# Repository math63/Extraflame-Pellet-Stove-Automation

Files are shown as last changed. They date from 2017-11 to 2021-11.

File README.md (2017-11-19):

# Extraflame-Pellet-Stove-Automation

https://pcbs.io/share/42JMy

https://www.sculpteo.com/fr/print_old/boite_v2-10/cqvDiYiF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

https://circuits.io/circuits/5604341-arduinorfm95-v6

Comments :
In mysensors plugin for jeedom, change baudrate from 115200 to 38400 :
Mysensors/Node/mysensors.js

```
var SerialPort = require('serialport');
	gw = new SerialPort(gwAddress);
        //compatibilité avec la nouvelle verion de serialport
        if ( gw.settings.baudRate ){
                gw.settings.baudRate=38400;
        }else{
                gw.settings.baudrate=38400;
        }
```

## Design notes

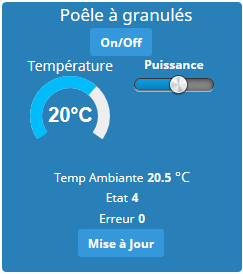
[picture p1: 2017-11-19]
Jeedom/Jeedom.png

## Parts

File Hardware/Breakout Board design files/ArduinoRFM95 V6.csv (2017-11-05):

Part | Value |  |  |  | Device | Package | Description | MPN | PROD_ID | VALUE
C1 | 0.1uF | 0603 0.1uF 50V 10% SMD Multilayer Ceramic Chip Capacitor | 0,0057 | aliexpress (seller don't exist anymore) | CAP0603-CAP | 0603-CAP | Capacitor
C2 | 0.1uF | 0603 0.1uF 50V 10% SMD Multilayer Ceramic Chip Capacitor | 0,0057 | aliexpress (seller don't exist anymore) | CAP0603-CAP | 0603-CAP | Capacitor
C3 | 0.1uF | 0603 0.1uF 50V 10% SMD Multilayer Ceramic Chip Capacitor | 0,0057 | aliexpress (seller don't exist anymore) | CAP0603-CAP | 0603-CAP | Capacitor
C4 | 10uF | Tantalum capacitor 10uf 16v type B 3528 (1210) | 0,13 |  | CAP_POL3528-KIT | EIA3528-KIT | Capacitor Polarized
C5 | 0.1uF | 0603 0.1uF 50V 10% SMD Multilayer Ceramic Chip Capacitor | 0,0057 | aliexpress (seller don't exist anymore) | CAP0603-CAP | 0603-CAP | Capacitor
C6 | 0.1uF | 0603 0.1uF 50V 10% SMD Multilayer Ceramic Chip Capacitor | 0,0057 | aliexpress (seller don't exist anymore) | CAP0603-CAP | 0603-CAP | Capacitor
C7 | 47pF |  |  |  | CAP0603-CAP | 0603-CAP | Capacitor
C8 | 47pF |  |  |  | CAP0603-CAP | 0603-CAP | Capacitor
C9 | 0.1uF | 0603 0.1uF 50V 10% SMD Multilayer Ceramic Chip Capacitor | 0,0057 | aliexpress (seller don't exist anymore) | CAP0603-CAP | 0603-CAP | Capacitor
C10 | 0.1uF | 0603 0.1uF 50V 10% SMD Multilayer Ceramic Chip Capacitor | 0,0057 | aliexpress (seller don't exist anymore) | CAP0603-CAP | 0603-CAP | Capacitor
C11 | 0.1uF | 0603 0.1uF 50V 10% SMD Multilayer Ceramic Chip Capacitor | 0,0057 | aliexpress (seller don't exist anymore) | CAP0603-CAP | 0603-CAP | Capacitor
C12 | 10uF | Tantalum capacitor 10uf 16v type B 3528 (1210) | 0,13 |  | CAP_POL3528-KIT | EIA3528-KIT | Capacitor Polarized
C13 | 1uF | 0603 1UF ceramic capacitor | 0,0086 | https://www.aliexpress.com/item/100PCS-0603-1UF-105-1000NF-10V-Y5V-Ceramic-capacitors-Good-Quality-and-ROHS/1091059510.html | CAP0603-CAP | 0603-CAP | Capacitor
C14 | 10uF | Tantalum capacitor 10uf 16v type B 3528 (1210) | 0,13 |  | CAP_POL3528-KIT | EIA3528-KIT | Capacitor Polarized
C15 | 0.1uF | 0603 0.1uF 50V 10% SMD Multilayer Ceramic Chip Capacitor | 0,0057 | aliexpress (seller don't exist anymore) | CAP0603-CAP | 0603-CAP | Capacitor
C16 | 18pF | GRM1885C1H180JA01J | 0,0418 | http://fr.farnell.com/murata/grm1885c1h180ja01j/condensateur-mlcc-c0g-18pf-50v/dp/2611915?CMP=i-bf9f-00001000 | CAP0603-CAP | 0603-CAP | Capacitor
C17 | 18pF | GRM1885C1H180JA01J | 0,0418 | http://fr.farnell.com/murata/grm1885c1h180ja01j/condensateur-mlcc-c0g-18pf-50v/dp/2611915?CMP=i-bf9f-00001000 | CAP0603-CAP | 0603-CAP | Capacitor
D1 | YELLOW | 0603 SMD LED Kits | 0,03 | https://www.aliexpress.com/item/0603-SMD-LED-Kits-Red-Yellow-Blue-Green-White-5-colors-each-20pcs/32552321637.html | LEDCHIP-LED0603 | CHIP-LED0603 | LED
D2 | RED | 0603 SMD LED Kits | 0,03 | https://www.aliexpress.com/item/0603-SMD-LED-Kits-Red-Yellow-Blue-Green-White-5-colors-each-20pcs/32552321637.html | LEDCHIP-LED0603 | CHIP-LED0603 | LED
F1 | MF-MSMF050-2 | MF-MSMF050-2 | 0,105 | https://www.aliexpress.com/item/10PCS-MF-MSMF050-2-MF-MSMF050-PTC-RESETTABLE-FUSE-0-5A-500MA-15V-For-BOURNS-1812/32633390844.html | SMD-PPTC-FUSE-PPTC-0.50A-15V-0.15OHM(1812) | F1812 | 307010040 | MF-MSMF050-2 |  | MF-MSMF050-2
FRAME1 | FRAME-LETTER |  |  |  | FRAME-LETTER | CREATIVE_COMMONS | Schematic Frame
J2 | AVR_SPI_PRG_6PTH | 2.54mm 2 x 40 Pin Male Double Row | 0,12 | https://www.aliexpress.com/item/5-PCS-2-54mm-2-x-40-Pin-Male-Double-Row-Pin-Header-Strip/32216818428.html | AVR_SPI_PRG_6PTH | 2X3 | AVR ISP 6 Pin
J3 | USB-SMD-NS | Mini USB Type B SMD Female Socket 5-Pin | 0,75 | aliexpress (seller don't exist anymore) | USB-SMD-NS | USB-MINIB-NOSTOP | USB Connectors
J4 |  |  |  |  | M161X16_NO_SILK | 1X16_NO_SILK | 1x16 .1 header"
J5 |  |  |  |  | M161X16_NO_SILK | 1X16_NO_SILK | 1x16 .1 header"
JP3 |  |  |  |  | M01NOSILK-KIT | 1X01NS-KIT | Header 1
Q1 | FDN360P | FDN360P | 0,362 | http://fr.farnell.com/on-semiconductor-fairchild/fdn360p/transistor-mosfet-p-sot-23/dp/9846336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 | MOSFET-PCHANNELSMD | SOT23-3 | Generic PMOSFET
Q2 | MOSFET-NCHANNEL2N7002PW |  |  |  | MOSFET-NCHANNEL2N7002PW | SOT323 | Common NMOSFET Parts |  | TRANS-11151
Q3 | PMV48XP | PMV48XP P-channel MOSFET | 0,19 | https://www.aliexpress.com/item/Free-shipping-10pcs-lot-PMV48XP-P-channel-MOSFET-FET-SOT-23-new-original/32558117050.html | MOSFET-PCHANNELSMD | SOT23-3 | Generic PMOSFET
R1 | 10K | Resistor 1% 0603 10K | 0,0044 | aliexpress (seller don't exist anymore) | RESISTOR0603-RES | 0603-RES | Resistor
R2 | 27R |  |  |  | RESISTOR0603-RES | 0603-RES | Resistor
R3 | 27R |  |  |  | RESISTOR0603-RES | 0603-RES | Resistor
R4 | 10K | Resistor 1% 0603 10K | 0,0044 | aliexpress (seller don't exist anymore) | RESISTOR0603 | 0603-RES | Resistor
R5 | 470R | 0603 1% 470 Ohm | 0,0034 | https://www.aliexpress.com/item/100pcs-bag-0603-1-4-7R-47R-470R-4-7K-47K-470K-5-1R-51R-510R/32815003609.html | RESISTOR0603-RES | 0603-RES | Resistor
R6 | 470R | 0603 1% 470 Ohm | 0,0034 | https://www.aliexpress.com/item/100pcs-bag-0603-1-4-7R-47R-470R-4-7K-47K-470K-5-1R-51R-510R/32815003609.html | RESISTOR0603-RES | 0603-RES | Resistor
R7 | 10K | Resistor 1% 0603 10K | 0,0044 | aliexpress (seller don't exist anymore) | RESISTOR0603-RES | 0603-RES | Resistor
R8 | 10K | Resistor 1% 0603 10K | 0,0044 | aliexpress (seller don't exist anymore) | RESISTOR0603-RES | 0603-RES | Resistor
R9 | 100K | Resistor 1% 0603 100K | 0,0044 | aliexpress (seller don't exist anymore) | RESISTOR0603-RES | 0603-RES | Resistor
U1 | ATMEGA328P_TQFP | ATMEGA328P-AU | 1,9 | http://fr.farnell.com/microchip/atmega328p-au/micro-8-bits-avr-32k-flash-32tqfp/dp/1715486?CMP=i-bf9f-00001000 | ATMEGA328P_TQFP | TQFP32-08 |  |  | IC-09069 | ATMEGA328P_TQFP
U2 | RFM95 | RFM95 868Mhz 20dBm | 8,26 | https://www.aliexpress.com/item/NEW-RFM95-20dBm-The-wireless-transceiver-module-RFM95-868MHZ/32613801519.html | RFM69HCW | RFM69HCW-XXXS2 |  |  | IC-11997, IC-12053
U3 | FT231XS | FT231XS-R | 2,32 | http://fr.farnell.com/ftdi/ft231xs/i-f-usb2-0-fs-to-f-l-h-s-uart/dp/2081328?CMP=i-bf9f-00001000 | FT231XS | SSOP20_L | FTDI FT231X Full Speed USB to Full-handshake UART |  | IC-11524 | FT231XS
U4 | NCP1117ST50T3G | NCP1117ST50T3G | 0,397 | http://fr.farnell.com/on-semiconductor/ncp1117st50t3g/regulateur-ldo-15vin-1a-5v-1-3sot223/dp/2112617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 | V_REG_LM1117SOT223 | SOT223 | Voltage Regulator LM1117 |  | VREG-08170
U5 | LP2992-33 | LP2992AIM5X-3.3 | 0,217 | https://www.aliexpress.com/item/Free-shipping-10pcs-lot-LP2992AIM5X-3-3-SOT23-5-LP2992AIM5-3-3-original-Product/32518298977.html | LP2992-3.3 | SOT-23-5 | LP2992-x
U6 | ATSHA204-TSU | ATSHA204A-STUCZ | 1,08 | https://www.aliexpress.com/item/Free-Shipping-5-PCS-LOT-ATSHA204A-STUCZ-T-ATSHA204A-STUCZ-ATSHA204A-SOT23-NEW-IN-STOCK/32630759618.html | ATSHA204-TSU | SOT23-3 | Atmel ATSHA204
X1 | SMA - 50 Ohm Connectors | 142-0711-821 | 5,31 | http://fr.farnell.com/johnson-cinch-connectivity/142-0711-821/conncetur-jack-sma/dp/1019328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 | SMACONNECTOR_EDGE_UFL | SMA_EDGELAUNCH_UFL | SMA Connector
XTAL | AMB7 | ABM7-8.000MHZ-D2Y-T | 0,73 | http://fr.farnell.com/abracon/abm7-8-000mhz-d2y-t/quartz-8mhz-18pf-cms/dp/2101337?CMP=i-bf9f-00001000 | AMB7 | 2-SMD_ABM7 | ABM7
 | Antenna

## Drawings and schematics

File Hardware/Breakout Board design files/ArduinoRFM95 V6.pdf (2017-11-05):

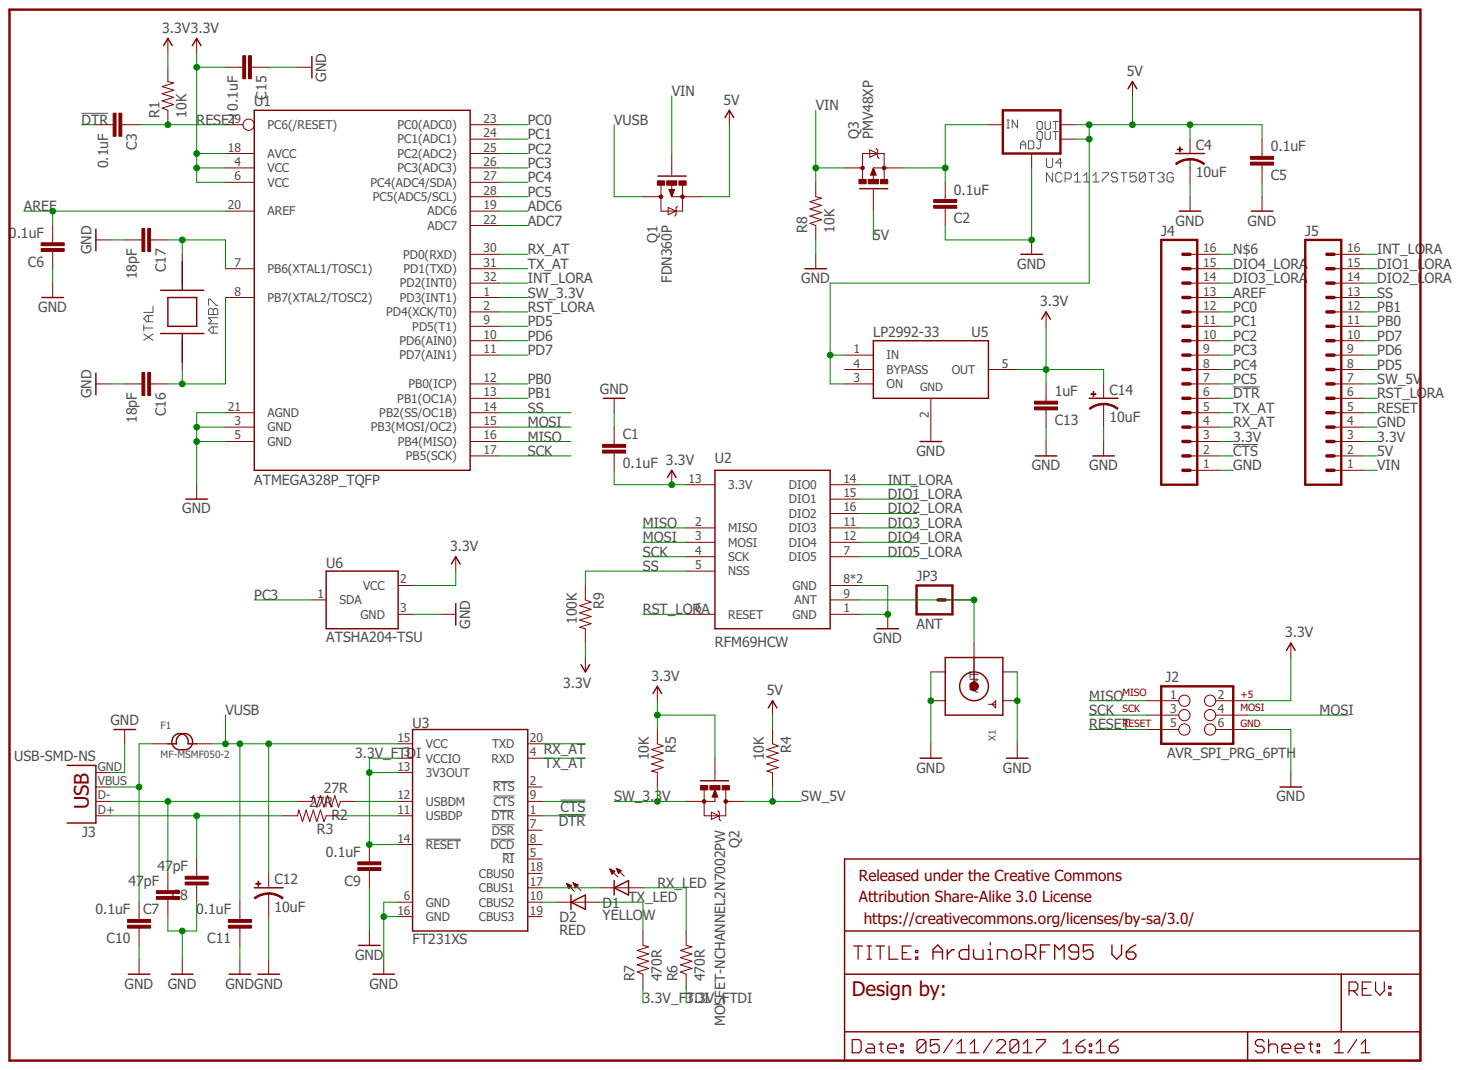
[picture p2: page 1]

Released under the Creative Commons Attribution Share-Alike 3.0 License https://creativecommons.org/licenses/by-sa/3.0/

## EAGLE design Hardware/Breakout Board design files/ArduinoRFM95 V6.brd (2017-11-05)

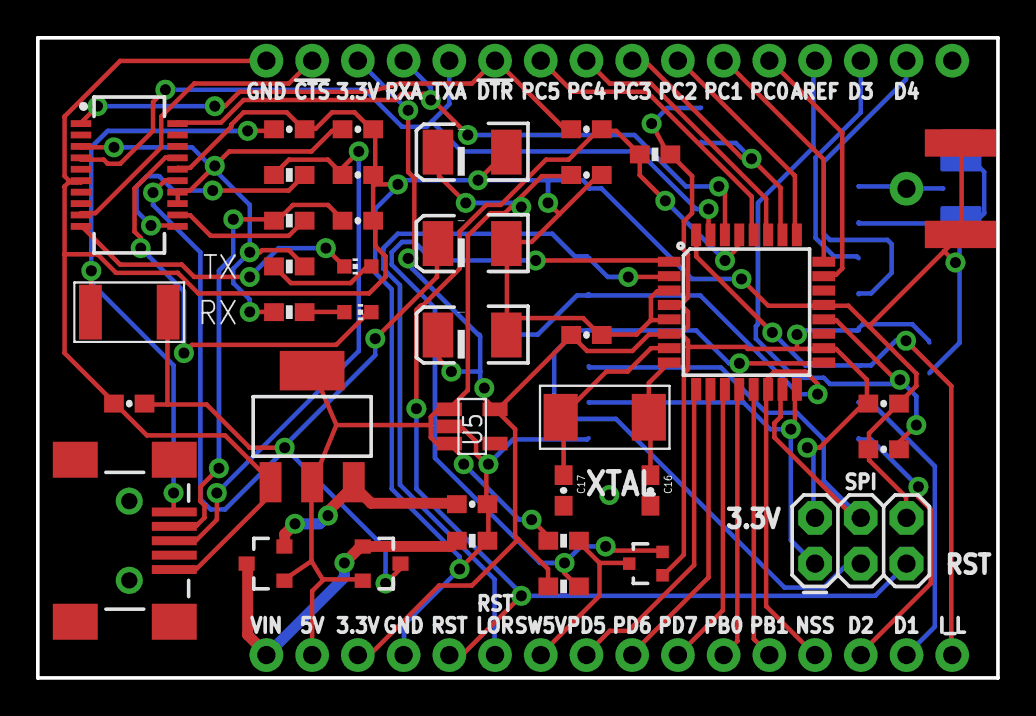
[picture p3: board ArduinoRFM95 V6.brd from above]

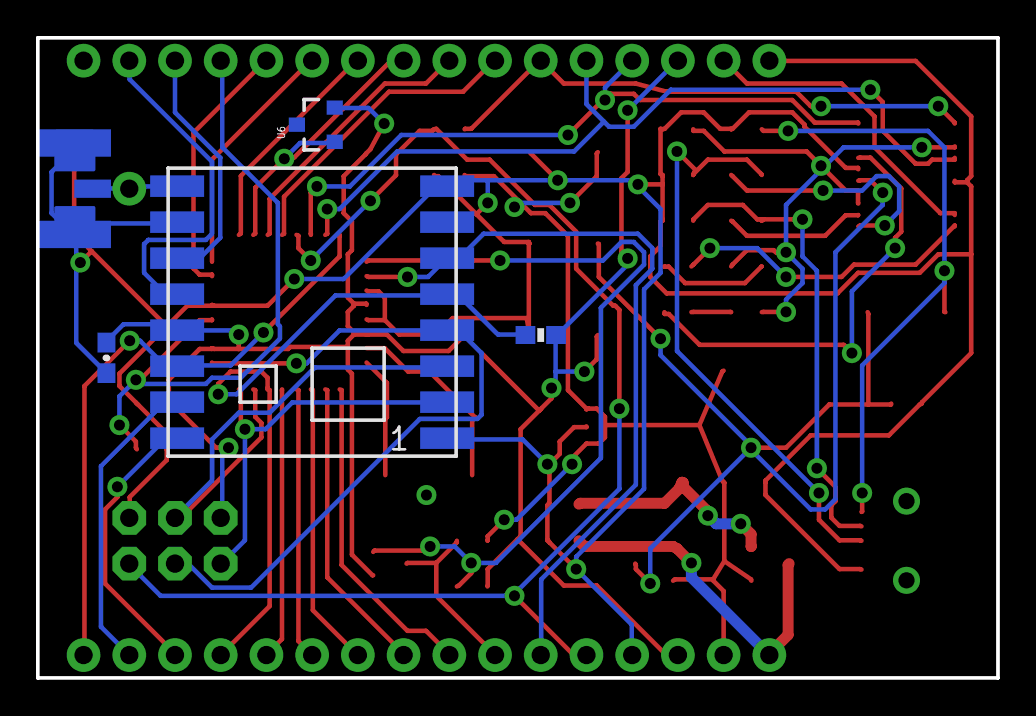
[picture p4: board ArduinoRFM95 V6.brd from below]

Board: 2 copper layers, 53.3 x 35.6 mm, 46 parts (5 on the bottom side), 48 nets.

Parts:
C1, C2, C3, C5, C6, C9, C10, C11, C15: 0.1uF; 0603-CAP
C4, C12, C14: 10uF; EIA3528-KIT
C7, C8: 47pF; 0603-CAP
C13: 1uF; 0603-CAP
C16, C17: 18pF; 0603-CAP
D1: YELLOW; CHIP-LED0603
D2: RED; CHIP-LED0603
F1: MF-MSMF050-2; F1812
FRAME1: FRAME-LETTER; CREATIVE_COMMONS
J2: AVR_SPI_PRG_6PTH; 2X3
J3: USB-SMD-NS; USB-MINIB-NOSTOP
J4, J5: 1X16_NO_SILK
JP3: 1X01NS-KIT
Q1: FDN360P; SOT23-3
Q2: MOSFET-NCHANNEL2N7002PW; SOT323
Q3: PMV48XP; SOT23-3
R1, R4, R5, R8: 10K; 0603-RES
R2, R3: 27R; 0603-RES
R6, R7: 470R; 0603-RES
R9: 100K; 0603-RES
U1: ATMEGA328P_TQFP; TQFP32-08
U2: RFM69HCW; RFM69HCW-XXXS2
U3: FT231XS; SSOP20_L
U4: NCP1117ST50T3G; SOT223
U5: LP2992-33; SOT-23-5
U6: ATSHA204-TSU; SOT23-3
X1: SMA_EDGELAUNCH_UFL
XTAL: AMB7; 2-SMD_ABM7

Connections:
3.3V: C1.2, C13.2, C14.A, C15.2, J2.2, J4.3, J5.3, Q2.1, R1.2, R5.1, R9.2, U1.4, U1.6, U1.18, U2.13, U5.5, U6.2
3.3V_FTDI: C9.2, R6.1, R7.1, U3.3, U3.13, U3.14
5V: C4.A, C5.2, J5.2, Q1.2, Q3.1, R4.1, U4.2, U4.4, U5.1, U5.3
!CTS: J4.2, U3.9
!DTR: C3.2, J4.6, U3.1
ANT: JP3.1, U2.9, X1.P
AREF: C6.2, J4.13, U1.20
DIO1_LORA: J5.15, U2.15
DIO2_LORA: J5.14, U2.16
DIO3_LORA: J4.14, U2.11
DIO4_LORA: J4.15, U2.12
GND: C1.1, C2.1, C4.C, C5.1, C6.1, C7.1, C8.1, C9.1, C10.1, C11.1, C12.C, C13.1, C14.C, C15.1, C16.2, C17.2, J2.6, J3.GND, J4.1, J5.4, R8.1, U1.3, U1.5, U1.21, U2.1, U2.8, U2.10, U3.6, U3.16, U4.1, U5.2, U6.3, X1.GND@1, X1.GND@2, X1.GND@3, X1.GND@4
INT_LORA: J5.16, U1.32, U2.14
MISO: J2.1, U1.16, U2.2
MOSI: J2.4, U1.15, U2.3
unnamed: R3.1, U3.11
unnamed: C7.2, J3.D-, R2.2
unnamed: C2.2, Q3.2, U4.3
unnamed: R2.1, U3.12
unnamed: C10.2, F1.1, J3.VBUS
unnamed: C17.1, U1.7, XTAL.P$2
unnamed: D2.C, U3.10
unnamed: C16.1, U1.8, XTAL.P$1
unnamed: C8.2, J3.D+, R3.2
unnamed: D1.C, U3.17
PB0: J5.11, U1.12
PB1: J5.12, U1.13
PC0: J4.12, U1.23
PC1: J4.11, U1.24
PC2: J4.10, U1.25
PC3: J4.9, U1.26, U6.1
PC4: J4.8, U1.27
PC5: J4.7, U1.28
PD5: J5.8, U1.9
PD6: J5.9, U1.10
PD7: J5.10, U1.11
RESET: C3.1, J2.5, J5.5, R1.1, U1.29
RST_LORA: J5.6, U1.2, U2.6
RX_AT: J4.4, U1.30, U3.20
RX_LED: D1.A, R6.2
SCK: J2.3, U1.17, U2.4
SS: J5.13, R9.1, U1.14, U2.5
SW_3.3V: Q2.2, R5.2, U1.1
SW_5V: J5.7, Q2.3, R4.2
TX_AT: J4.5, U1.31, U3.4
TX_LED: D2.A, R7.2
VIN: J5.1, Q1.1, Q3.3, R8.2
VUSB: C11.2, C12.A, F1.2, Q1.3, U3.15

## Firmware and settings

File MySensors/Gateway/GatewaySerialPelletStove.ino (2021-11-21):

/**
* The MySensors Arduino library handles the wireless radio link and protocol
* between your home built sensors/actuators and HA controller of choice.
* The sensors forms a self healing radio network with optional repeaters. Each
* repeater and gateway builds a routing tables in EEPROM which keeps track of the
* network topology allowing messages to be routed to nodes.
*
* Created by Henrik Ekblad <henrik.ekblad@mysensors.org>
* Copyright (C) 2013-2015 Sensnology AB
* Full contributor list: https://github.com/mysensors/Arduino/graphs/contributors
*
* Documentation: http://www.mysensors.org
* Support Forum: http://forum.mysensors.org
*
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
*******************************
*
* DESCRIPTION
* The ArduinoGateway prints data received from sensors on the serial link.
* The gateway accepts input on seral which will be sent out on radio network.
*
* The GW code is designed for Arduino Nano 328p / 16MHz
*
* Wire connections (OPTIONAL):
* - Inclusion button should be connected between digital pin 3 and GND
* - RX/TX/ERR leds need to be connected between +5V (anode) and digital pin 6/5/4 with resistor 270-330R in a series
*
* LEDs (OPTIONAL):
* - To use the feature, uncomment any of the MY_DEFAULT_xx_LED_PINs
* - RX (green) - blink fast on radio message recieved. In inclusion mode will blink fast only on presentation recieved
* - TX (yellow) - blink fast on radio message transmitted. In inclusion mode will blink slowly
* - ERR (red) - fast blink on error during transmission error or recieve crc error
*
*/

// Enable debug prints to serial monitor
#define MY_DEBUG
#define MY_DEBUG_VERBOSE_RFM95

// Enable and select radio type attached
//#define MY_RADIO_NRF24
#define MY_RADIO_RFM95

#define MY_RFM95_CS_PIN 4 // NSS carte atmega1284p
#define MY_RFM95_IRQ_PIN 2 // IRQ D100
//#define MY_RFM95_RST_PIN 4

// Set LOW transmit power level as default, if you have an amplified NRF-module and
// power your radio separately with a good regulator you can turn up PA level.
//#define MY_RF24_PA_LEVEL RF24_PA_LOW

// Enable serial gateway
#define MY_GATEWAY_SERIAL

// Define a lower baud rate for Arduino's running on 8 MHz (Arduino Pro Mini 3.3V & SenseBender)
#if F_CPU == 8000000L
#define MY_BAUD_RATE 38400
#endif

// Enable inclusion mode
#define MY_INCLUSION_MODE_FEATURE
// Enable Inclusion mode button on gateway
//#define MY_INCLUSION_BUTTON_FEATURE

// Inverses behavior of inclusion button (if using external pullup)
//#define MY_INCLUSION_BUTTON_EXTERNAL_PULLUP

// Set inclusion mode duration (in seconds)
#define MY_INCLUSION_MODE_DURATION 60
// Digital pin used for inclusion mode button
//#define MY_INCLUSION_MODE_BUTTON_PIN  3

// Set blinking period
//#define MY_DEFAULT_LED_BLINK_PERIOD 300

// Inverses the behavior of leds
//#define MY_WITH_LEDS_BLINKING_INVERSE

// Flash leds on rx/tx/err
// Uncomment to override default HW configurations
//#define MY_DEFAULT_ERR_LED_PIN 4  // Error led pin
//#define MY_DEFAULT_RX_LED_PIN  6  // Receive led pin
//#define MY_DEFAULT_TX_LED_PIN  5  // the PCB, on board LED

#include <MySensors.h>
#include <Wire.h>
#include <Adafruit_Sensor.h>
#include "Adafruit_BME680.h"

#define PELLET_NODE_ID  1

MyMessage msgGw2Node(0,V_CUSTOM);
//
//
MyMessage msgtempc(11,V_HVAC_SETPOINT_HEAT);
MyMessage msgpower(12,V_VAR3);
MyMessage msgprog(15,V_STATUS);
MyMessage msgstand(16,V_STATUS);
//
//
MyMessage msgtempa(20,V_TEMP);
MyMessage msgetat(21,V_TEXT);
MyMessage msgerreur(22,V_TEXT);
MyMessage msgtempfum(23,V_TEMP);
MyMessage msgtempres(24,V_TEMP);
MyMessage msgtempinair(25,V_TEMP);
MyMessage msgcadvis(26,V_VAR1);
MyMessage msgvitfum(27,V_VAR1);
MyMessage msgdurphase(28,V_VAR2);
MyMessage msgflux(29,V_VAR4);
MyMessage msgpowerreal(30,V_VAR3);

//
//
MyMessage temperatureMsg(40, V_TEMP);
MyMessage humidityMsg(41, V_HUM);
MyMessage pressureMsg(42, V_PRESSURE);
//                   0      1           2                         3                   4                     5           6                 7           8                         9               
//  String MsgEtat[]={"Off","Démarrage","Allumage - Charg pellet","Démarrage Flamme","Travail - Modulation","Nettoyage","Nettoyage Final","Stand-by","Erreur, Refroidissement","Erreur, Off"};
 const char* MsgEtat[]={"Off","Demarrage","Allumage-Charg","Dem Flamme","Travail-Modul","Nettoyage","Nettoyage Final","Stand-by","Erreur, Refroidissement","Erreur, Off"};
//                     0   1   2   3   4   5   6   7   8               9   10   11   12   13   14   15   16                 17   18
//  String MsgErreur[]={"-","1","2","3","4","5","6","7","Allumage Raté","9","10","11","12","13","14","15","Pellets terminés","17","18"};
 const char* MsgErreur[]={"-","No All Black-Out","Sonde Fumee","Temp Fumees","Asp Fumees KO","Allumage Rate","Pellets term","Depression","No Flux","Err inconnue"};

Adafruit_BME680 bme; // I2C

unsigned long delayTime;
  
void setup()
{
	// Setup locally attached sensors
 
  if (!bme.begin()) {
    Serial.println("Could not find a valid BME680 sensor, check wiring!");
    while (1);
  }
  // weather monitoring
  
  // Set up oversampling and filter initialization
  
  bme.setTemperatureOversampling(BME680_OS_1X);
  bme.setHumidityOversampling(BME680_OS_1X);
  bme.setPressureOversampling(BME680_OS_1X);
  bme.setIIRFilterSize(BME680_FILTER_SIZE_0);  
  bme.setGasHeater(0, 0); // 320*C for 150 ms

  
                     
    // suggested rate is 1/60Hz (1m)
    delayTime = 60000; // in milliseconds
}

void presentation()
{
//  wait(30000);
sendSketchInfo("Pellet STOVE GW", "2.2");
  // Present locally attached sensors
  
//  present(10, S_HEATER); //commande  V_STATUS : on/off
//  present(11, S_HEATER); //commande V_HVAC_SETPOINT_HEAT : consigne temp
// present(12, S_HEATER); //commande V_VAR3 : consigne power
//  present(13, S_HEATER); //commande V_STATUS : actualisation
//  present(14, S_HEATER); //commande V_STATUS : Reset node
//  present(15, S_HEATER); //commande V_STATUS : prog
  
//  present(20, S_HEATER); //info V_TEMP : temp ambiant
//  present(21, S_HEATER); //info V_TEXT : Etat
//  present(22, S_HEATER); //info V_TEXT : Erreur
  
//    present(30, S_TEMP);
//    present(31, S_HUM);
//    present(32, S_BARO);
  
}

void loop()
{
  // Send locally attached sensor data here

  if (! bme.performReading()) {
    Serial.println("Failed to perform reading :(");
    return;
  }
send(temperatureMsg.set(bme.temperature, 1));
send(humidityMsg.set(bme.humidity, 1));
send(pressureMsg.set(bme.pressure/100.0, 1));

wait(delayTime);
}

void receive(const MyMessage &message)
{
	if(message.sender == 0){
switch(message.sensor)
{	uint8_t datasent[2];
	case 10 : //on-off
	datasent[0]=1;
	datasent[1]=(uint8_t) message.getBool();
	send(msgGw2Node.setDestination(PELLET_NODE_ID).set(datasent,2));
		break;
	case 11 : // consigne temp
	datasent[0]=2;
	datasent[1]=(uint8_t) message.getFloat();
	send(msgGw2Node.setDestination(PELLET_NODE_ID).set(datasent,2));
		break;
	case 12 : // consigne power
	datasent[0]=3;
	datasent[1]=(uint8_t) message.getFloat();
	send(msgGw2Node.setDestination(PELLET_NODE_ID).set(datasent,2));
		break;
	case 13 : // Actualisation
	datasent[0]=4;
	datasent[1]=(uint8_t) message.getBool();
	send(msgGw2Node.setDestination(PELLET_NODE_ID).set(datasent,2));
		break;
	case 14 : // reset
	datasent[0]=5;
	datasent[1]=(uint8_t) message.getBool();
	send(msgGw2Node.setDestination(PELLET_NODE_ID).set(datasent,2));
		break;
  case 15 : // Programmation on/off
  datasent[0]=6;
  datasent[1]=(uint8_t) message.getBool();
  send(msgGw2Node.setDestination(PELLET_NODE_ID).set(datasent,2));
    break;
   case 16 : // Stand-by on-off
  datasent[0]=7;
  datasent[1]=(uint8_t) message.getBool();
  send(msgGw2Node.setDestination(PELLET_NODE_ID).set(datasent,2));
    break;
  case 17 : // MAJ date/heures
  datasent[0]=8;
  datasent[1]=(uint8_t) message.getBool();
  send(msgGw2Node.setDestination(PELLET_NODE_ID).set(datasent,2));
    break;
  case 18 : // Exploration RAM par lignes
  datasent[0]=9;
  datasent[1]=(uint8_t) message.getFloat();
  send(msgGw2Node.setDestination(PELLET_NODE_ID).set(datasent,2));
    break;
  case 19 : // Exploration ROM par lignes
  datasent[0]=10;
  datasent[1]=(uint8_t) message.getFloat();
  send(msgGw2Node.setDestination(PELLET_NODE_ID).set(datasent,2));
    break;
    
		
	default : 
	Serial.println("Erreur de commande");
	break;
	
}
} else if(message.sender == PELLET_NODE_ID && message.type== V_CUSTOM && message.sensor==1 ){
	
	uint8_t* data=(uint8_t*)message.getCustom();
	if (message.version_length>>3 == 13)
	{
		uint8_t tempc=0;
	  uint8_t tempa=0;
	  uint8_t power=0;
	  uint8_t etat=0;
	  uint8_t erreur=0;
    uint8_t prog=0;
    uint8_t stand=0;
    uint8_t temp_fum=0;
    uint8_t temp_res=0;
    uint8_t temp_inair=0;
    uint8_t cad_vis=0;
    uint8_t vit_fum=0;
    uint8_t dur_phase=0;
    uint8_t flux=0;
    uint8_t power_real=0;
 
	tempc =  data[0];
	tempa = data[1];
	power =  data[2]>>4 ;
	etat = data[2]& 0b00001111;
  prog = data[3]>>7;
  stand = (data[3]& 0b01000000)>>6 ;
	erreur = data[4];
  temp_fum = data[5];
	temp_res = data[6];
  temp_inair = data[7];
  cad_vis = data[8];
  vit_fum = data[9];
  dur_phase = data[10];
  flux = data[11];
  power_real = data[12];
  
	send(msgtempa.set(tempa/2.0,1));
	send(msgetat.set(MsgEtat[etat]));
	send(msgerreur.set(MsgErreur[transError(erreur)]));
	send(msgpower.set(power));
	send(msgtempc.set(tempc));
  send(msgprog.set(prog));
  send(msgstand.set(stand));
  send(msgtempfum.set(temp_fum));
  send(msgtempres.set(temp_res));
  send(msgtempinair.set(temp_inair/2.0-15.0,1));
  send(msgcadvis.set(cad_vis/40.0,1));
  send(msgvitfum.set(vit_fum*10+250));
  send(msgdurphase.set(dur_phase));
  send(msgflux.set(flux/10.0,1));
  send(msgpowerreal.set(power_real));
   
}
} else if(message.sender == PELLET_NODE_ID && message.type== V_CUSTOM && message.sensor==2 ){
  
	
} else if(message.sender == PELLET_NODE_ID && message.type== V_CUSTOM && message.sensor==3 ){
	
}
}

uint8_t transError(uint8_t erreur) {
  uint8_t error_tab;
  switch(erreur) {
  case 0 : // pas d'erreur
  error_tab= 0;
    break; 
  case 255 : // All black out
  error_tab= 1;
    break; 
  case 1 : // Sonde Fumee
  error_tab= 2;
    break; 
   case 2 : // Temp Fumees
  error_tab= 3;
    break;
  case 4 : // Asp Fumees KO
  error_tab= 4;
    break;
  case 8 : // Allumage Rate
  error_tab= 5;
    break;
  case 16 : // Pellets term
  error_tab= 6;
    break;
  case 32 : // Depression
  error_tab= 7;
   break;
  case 64 : // No Flux
  error_tab= 8;
    break;
  default : 
  error_tab = 9;
  break;
  }
  return error_tab;
}

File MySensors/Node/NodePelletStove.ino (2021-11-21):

  /**
 * The MySensors Arduino library handles the wireless radio link and protocol
 * between your home built sensors/actuators and HA controller of choice.
 * The sensors forms a self healing radio network with optional repeaters. Each
 * repeater and gateway builds a routing tables in EEPROM which keeps track of the
 * network topology allowing messages to be routed to nodes.
 *
 * Created by Henrik Ekblad <henrik.ekblad@mysensors.org>
 * Copyright (C) 2013-2015 Sensnology AB
 * Full contributor list: https://github.com/mysensors/Arduino/graphs/contributors
 *
 * Documentation: http://www.mysensors.org
 * Support Forum: http://forum.mysensors.org
 *
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
 *******************************
 *
 * REVISION HISTORY
 * Version 1.0 - Henrik Ekblad
 *
 * DESCRIPTION
 * Example sketch showing how to control physical relays.
 * This example will remember relay state after power failure.
 * http://www.mysensors.org/build/relay
 */

// Enable debug prints to serial monitor
#define MY_DEBUG
#define MY_DEBUG_VERBOSE_RFM95
#define STOVE_DEBUG

// Enable and select radio type attached
#define MY_RADIO_RFM95

#define MY_NODE_ID 1

#include <MySensors.h>
#include <single_wire_UART.h>
#include <avr/wdt.h>
#include <TimeLib.h> 

#define soft_reset()        \
do                          \
{                           \
    wdt_enable(WDTO_15MS);  \
    for(;;)                 \
    {                       \
    }                       \
} while(0)

// Wait time between updates (in milliseconds)
static const uint64_t WAIT_TIME = 600000;
// Time between sedning and receiving data from stove
static const uint64_t PEL_TIME= 25;


uint8_t uiBufferRtx[] = {0x00,0x00};
uint8_t uiBufferRrx[] = {0x00,0x00};

static MyMessage MsgNo2Gw_std(1,V_CUSTOM);
static MyMessage MsgNo2Gw_prog(2,V_CUSTOM);
static MyMessage MsgNo2Gw_para(3,V_CUSTOM);
static MyMessage MsgNo2Gw_deb(4,V_CUSTOM);

void before()
{

}

void setup()
{
  wait(30000);// wait while stove is booting
#ifdef STOVE_DEBUG
  Serial.println("Démarrage communication pellet stove ");
#endif

  SW_UART_Enable();

}

void presentation()
{
	// Send the sketch version information to the gateway and Controller
	sendSketchInfo("NodePelletStove", "2.2");
}


void loop()
{
  
Read_Send_Stove_Std_data();

wait(WAIT_TIME);
}

void receive(const MyMessage &message)
{
  
	if (message.sender== 0 && message.type==V_CUSTOM){
	static uint8_t* data=(uint8_t*)message.getCustom();
	if (message.version_length>>3 == 2 ){
	switch(data[0])
{	
	case 1 : //on-off
	#ifdef STOVE_DEBUG
	Serial.print("Bouton On/Off selectionné ");
	#endif
	repetition(0x80,0x58,0x5A,10,140);
	wait(PEL_TIME);
	Read_Send_Stove_Std_data();
		break;
	case 2 : // consigne temp
	#ifdef STOVE_DEBUG
	Serial.print("Message recu Temp Consigne = ");
	Serial.println(data[1]);
	#endif
	bWriteStove(0xA0, 0x7D,data[1]);
	wait(PEL_TIME);
	Read_Send_Stove_Std_data();
		break;
	case 3 : // consigne power
	#ifdef STOVE_DEBUG
	Serial.print("Message recu Power Consigne = ");
	Serial.println(data[1]);
	#endif
	bWriteStove(0xA0, 0x7F,data[1]);
	wait(PEL_TIME);
	Read_Send_Stove_Std_data();
		break;
  	case 4 : // refresh
	#ifdef STOVE_DEBUG
	Serial.print("Demande Mise à jour données ");
	#endif
	Read_Send_Stove_Std_data();
		break;
	case 5 : // reset
	#ifdef STOVE_DEBUG
	Serial.print("Reseting Node");
	#endif
  soft_reset();
  while(true){}
		break;
	case 6 : // Activation/Desactivation Programmation quotidienne
		#ifdef STOVE_DEBUG
	Serial.print("Changement état Programmation quotidienne : ");
	Serial.println(data[1]);
	#endif
	bWriteStove(0xA0, 0x4C, data[1]);
	wait(PEL_TIME);
	Read_Send_Stove_Std_data();
    break;  
   case 7 : // Activation/Desactivation fonction stand-by
    #ifdef STOVE_DEBUG
  Serial.print("Changement état fonction stand-by : ");
  Serial.println(data[1]);
  #endif
  bWriteStove(0xA0, 0x45, data[1]);
  wait(PEL_TIME);
  Read_Send_Stove_Std_data();
    break;  
    
   case 8 : // Mise à jour heure
  requestTime();
    break;

   case 9 : // Exploration RAM par lignes
   {
  #ifdef STOVE_DEBUG
  Serial.print("Exploration RAM de la lignes  : ");
  Serial.println(data[1]);
  #endif
  uint8_t debug[16]={0};
  
   for(uint8_t j=0;j <= 15;j++){
    bReadStove(0x00,data[1]*16+j);
    debug[j] = uiBufferRrx[1];
    wait(PEL_TIME);
   } 
   send(MsgNo2Gw_deb.set(debug,16));
   }
    break;

   case 10 : // Exploration ROM par lignes
    {
  #ifdef STOVE_DEBUG
  Serial.print("Exploration ROM de la lignes  : ");
  Serial.println(data[1]);
  #endif
  uint8_t debug[16]={0};
  
   for(uint8_t j=0;j <= 15;j++){
    bReadStove(0x20,data[1]*16+j);
    debug[j] = uiBufferRrx[1];
    wait(PEL_TIME);
   } 
   send(MsgNo2Gw_deb.set(debug,16));
    }
    break;
    
	default : 
	#ifdef STOVE_DEBUG
	Serial.println("Erreur de commande");
	#endif
	break;
	
}
	
	}
	}
}
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

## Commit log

2017-10-22 add lib
    [ArduinoRFM95 V6.brd, ArduinoRFM95 V6.sch]
2017-11-02 circuits.io link added

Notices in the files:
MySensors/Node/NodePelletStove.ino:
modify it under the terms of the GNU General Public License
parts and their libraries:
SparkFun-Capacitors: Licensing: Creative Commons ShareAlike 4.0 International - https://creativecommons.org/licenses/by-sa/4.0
